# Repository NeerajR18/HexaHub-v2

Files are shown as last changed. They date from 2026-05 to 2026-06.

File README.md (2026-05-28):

Zine

# HexaHub-v2

NOTE: This is still a WIP project. Follow at your own risk!

A USB 2.0 Hub using the SL2.1A which has 4 downstream USB-A port and USB-C upstream port, with ESD and overcurrent protection enclosed in a 3D printed case with a hexagon-shaped PCB.

This USB Hub was made because of unavailability of the SL2.1S IC, which was used in the previous version and also as an improved version with polyfuses and ESD protection diodes.

This Hub was designed using KiCad and Autodesk Fusion for PCB and CAD Design. Fusion was also used for the case renders.

Made for Hack Club Fallout.

# PCB

- Schematic


- PCB without Ground Plane


- Overall PCB


# CAD

- Full Assembly


- Exploded View


# Renders
- Enclosed
HexahubV2_2026-May-25_07-50-50AM-000_CustomizedView698346096
- Exploded
HexahubV2_2026-May-25_08-39-06AM-000_CustomizedView19009070130

# Build Guide
- Acquire your parts from your favourite platform.
- Order the PCB from your manufacturer
- Solder the components to the PCB
- 3D print the case, place PCB in the bottom, then close the top.
- Done!
If any footprints or 3D models are missing, you may use the footprints, symbols etc. from the Assets folder. Check your project folder and paths before importing.

# Bill of Materials

| MPN | Designator | Package | Quantity | Unit Price | Price (Ext.) | LCSC Link |
|---|---|---|---|---|---|---|
| SL2.1A | U1 | SOP-16 | 5 | 0.2677 | 1.34 | https://www.lcsc.com/product-detail/C6798314.html |
| 10.0 QHHTZB6.3 | J1 | SMD | 10 | 0.0665 | 0.67 | https://www.lcsc.com/product-detail/C668591.html |
| 676430910 | J2, J3, J4, J5 | Through Hole, Right Angle | 4 | 0.9415 | 3.77 | https://www.lcsc.com/product-detail/C2798029.html |
| 1206L200/24NR | F1 | 1206 | 5 | 0.1404 | 0.70 | https://www.lcsc.com/product-detail/C42396578.html |
| 1206L005/110WR | F2, F3, F4, F5 | 1206 | 5 | 0.1387 | 0.69 | https://www.lcsc.com/product-detail/C46422913.html |
| PRTR5V0U2X-ES | D1, D2, D3, D4, D5 | SOT-143 | 5 | 0.0404 | 0.20 | https://www.lcsc.com/product-detail/C5180302.html |
| X32258MOB4SI | Y1 | SMD3225-4P | 5 | 0.1738 | 0.87 | https://www.lcsc.com/product-detail/C2682775.html |
| RC0603FR-075K1L | R1, R2 | 0603 | 100 | 0.0018 | 0.18 | https://www.lcsc.com/product-detail/C105580.html |
| CL10A106KP8NNNC | C1, C2, C3, C4, C5, C6 | 0603 | 20 | 0.0108 | 0.22 | https://www.lcsc.com/product-detail/C19702.html |
| CC0402JRNPO9BN220 | C7, C8 | 0402 | 100 | 0.0012 | 0.12 | https://www.lcsc.com/product-detail/C106203.html |
| JLCPCB(PCB+shipping) | - | - | 5 | 4.66 | 14 | jlcpcb.com
| Total | - | - | - | 22.76 | - |
Apart from the IC, you may choose any brand of parts but with same package.

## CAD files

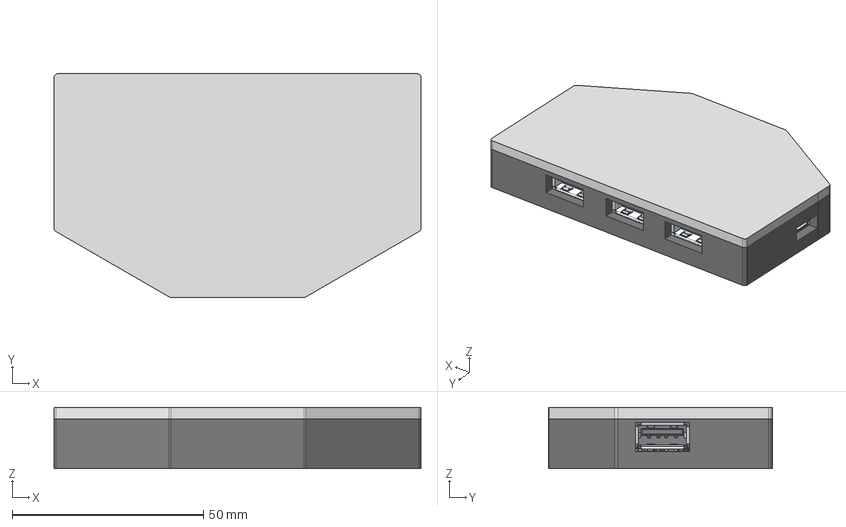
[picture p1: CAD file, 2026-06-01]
CAD/HexahubV2-assembled.step
96.0 x 58.5 x 16.0 mm

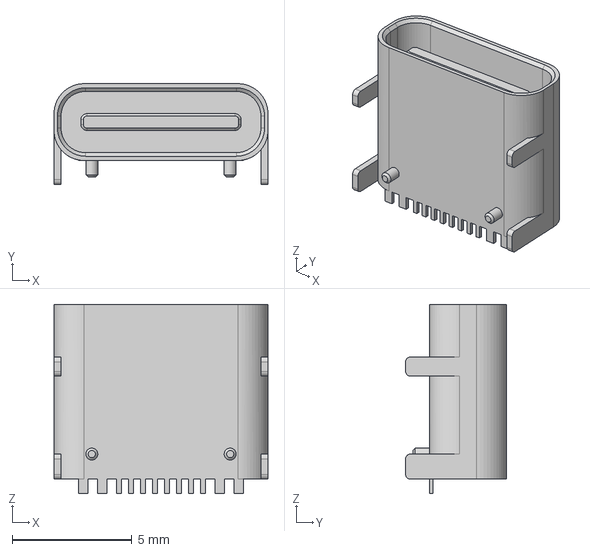
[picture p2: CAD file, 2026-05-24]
Assets/Type-C/HRO TYPE-C-31-M-12.step
8.94 x 4.21 x 7.90 mm

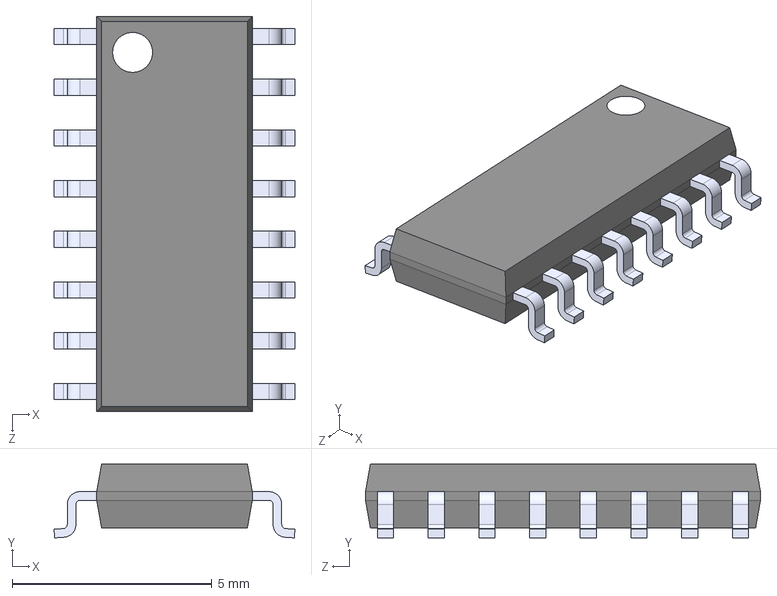
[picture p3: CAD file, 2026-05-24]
PCB/SL2.1A/SL2.1A.step
6.04 x 1.85 x 9.90 mm

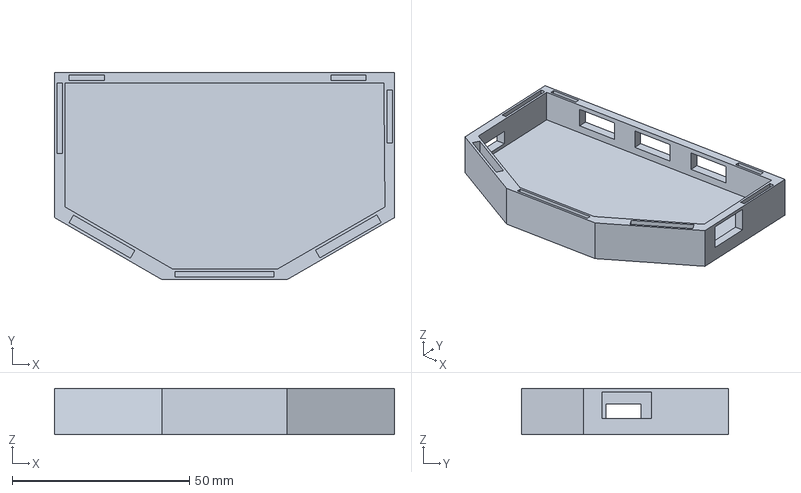
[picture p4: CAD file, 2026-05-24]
Production/STEP files/HexahubV2-bottom.step
96.0 x 58.5 x 13.0 mm
C_0402_1005Metric x 2
SOT-143 x 5
SL2.1A
Fuse_1206_3216Metric x 5
C_0603_1608Metric x 6
R_0603_1608Metric x 2
USB_A_Molex_67643_Horizontal x 4
Crystal_SMD_3225-4Pin_3.2x2.5mm
HRO TYPE-C-31-M-12
HexaHubV2_copper
HexaHubV2_PCB

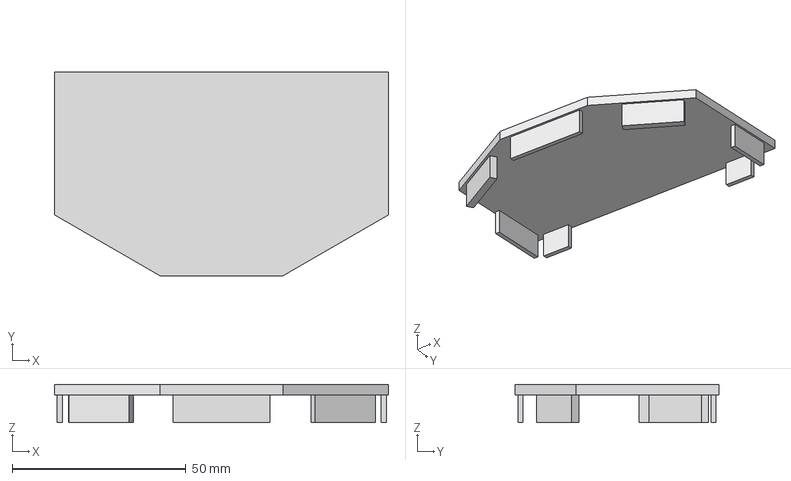
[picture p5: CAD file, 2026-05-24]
Production/STEP files/HexahubV2-top.step
96.0 x 58.5 x 11.0 mm
C_0402_1005Metric x 2
SOT-143 x 5
SL2.1A
Fuse_1206_3216Metric x 5
C_0603_1608Metric x 6
R_0603_1608Metric x 2
USB_A_Molex_67643_Horizontal x 4
Crystal_SMD_3225-4Pin_3.2x2.5mm
HRO TYPE-C-31-M-12
HexaHubV2_copper
HexaHubV2_PCB

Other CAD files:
CAD/HexahubV2-top.step
CAD/HexahubV2-bottom.step
CAD/HexahubV2.f3z
Production/STL files/HexahubV2-bottom.stl
Production/STL files/HexahubV2-top.stl

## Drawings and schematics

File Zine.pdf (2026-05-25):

V2

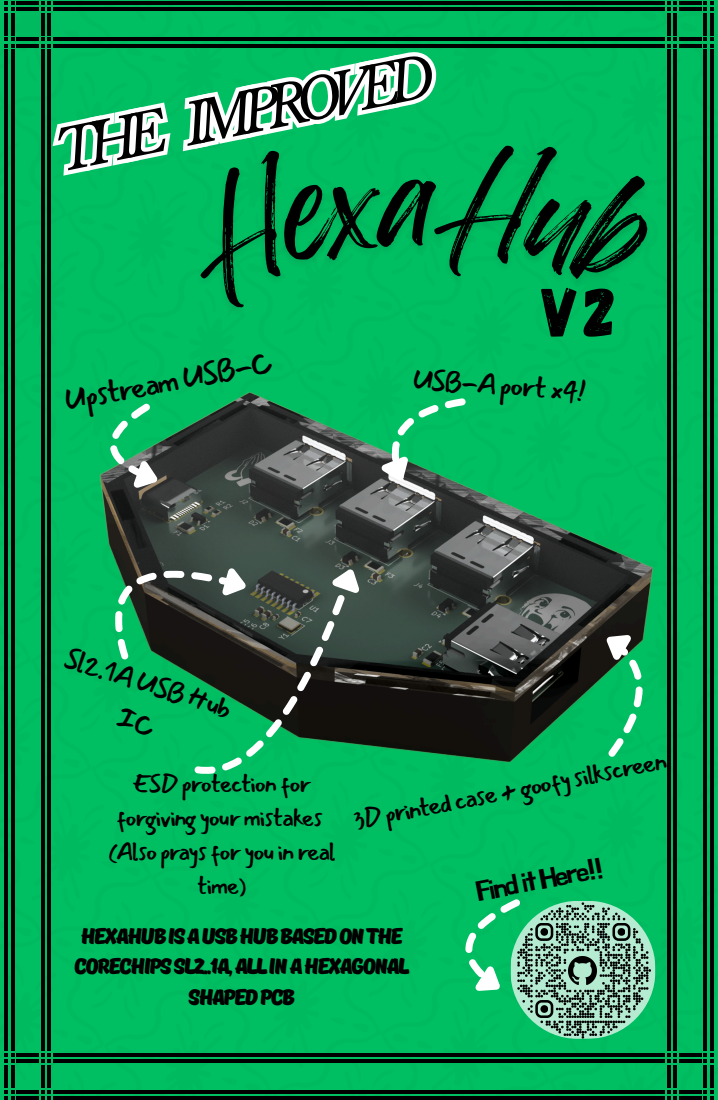
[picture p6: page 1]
UpstreamUSB-C; USBHub C; USB-Aportx4!; 3Dprintedcase+goofysilkscreen; ESDprotectionfor forgivingyourmistakes (Alsopraysforyouinreal time); HexaHubisaUSBHubbasedonthe CoreChipsSL2..1A,allinahexagonal shapedPCB; FinditHere!!

THE IMPROVED IMPROVED

THE IMPROVED HexaHub

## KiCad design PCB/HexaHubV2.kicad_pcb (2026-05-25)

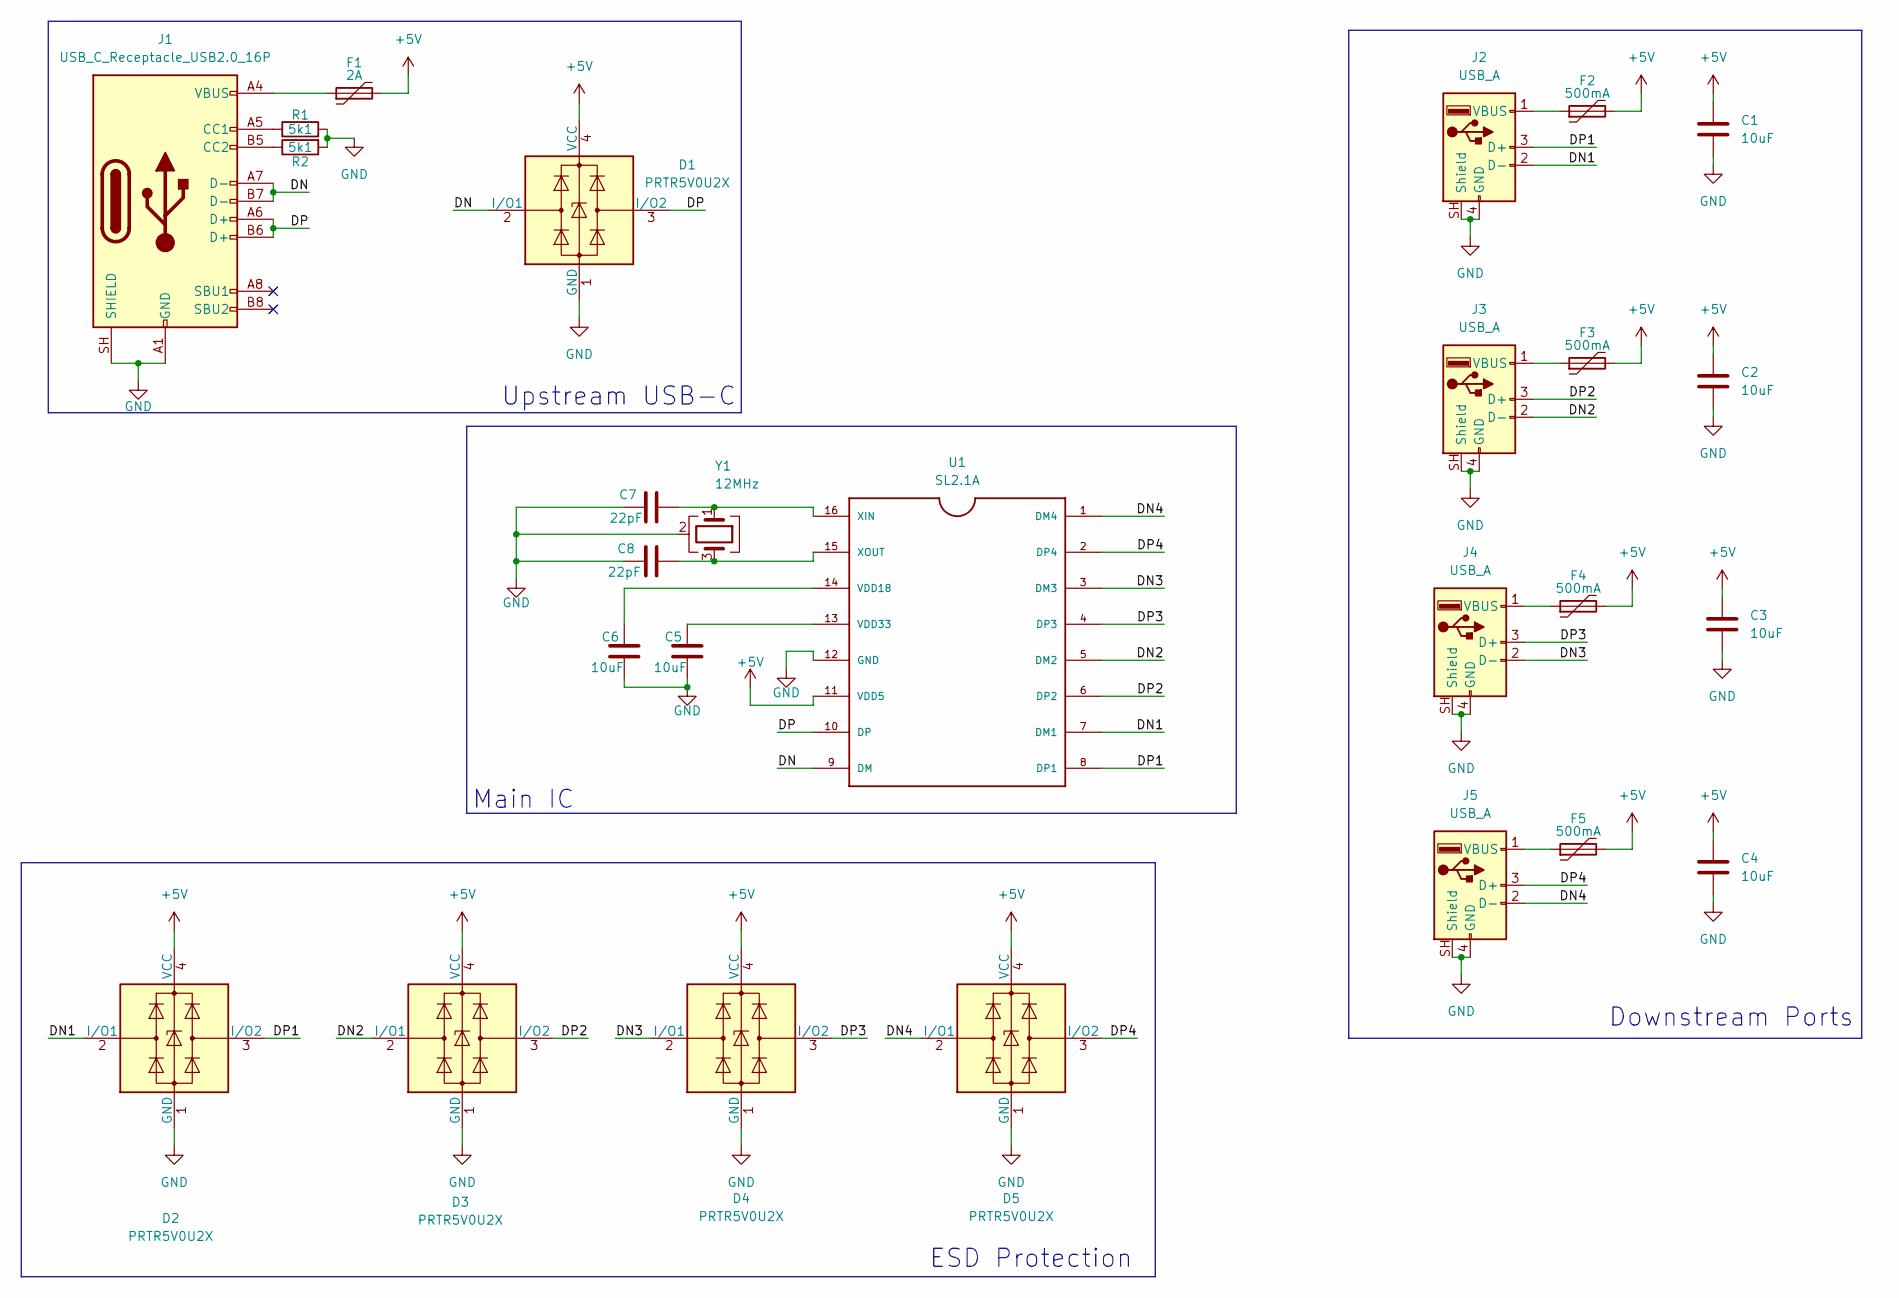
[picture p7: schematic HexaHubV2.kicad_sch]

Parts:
C1, C2, C3, C4, C5, C6: 10uF; C_0603_1608Metric
C7, C8: 22pF; C_0402_1005Metric
D1, D2, D3, D4, D5: PRTR5V0U2X; SOT-143
F1: 2A; Fuse_1206_3216Metric
F2, F3, F4, F5: 500mA; Fuse_1206_3216Metric
J1: USB_C_Receptacle_USB2.0_16P; USB_C_Receptacle_HRO_TYPE-C-31-M-12
J2, J3, J4, J5: USB_A; USB_A_Molex_67643_Horizontal
R1, R2: 5k1; R_0603_1608Metric
U1: SL2.1A; SO16
Y1: 12MHz; Crystal_SMD_3225-4Pin_3.2x2.5mm

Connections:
+5V: C1.1, C2.1, C3.1, C4.1, D1.4 (VCC), D2.4 (VCC), D3.4 (VCC), D4.4 (VCC), D5.4 (VCC), F1.2, F2.2, F3.2, F4.2, F5.2, U1.11 (VDD5)
/DN: D1.2 (I/O1), J1.A7 (D-), J1.B7 (D-), U1.9 (DM)
/DN1: D2.2 (I/O1), J2.2 (D-), U1.7 (DM1)
/DN2: D3.2 (I/O1), J3.2 (D-), U1.5 (DM2)
/DN3: D4.2 (I/O1), J4.2 (D-), U1.3 (DM3)
/DN4: D5.2 (I/O1), J5.2 (D-), U1.1 (DM4)
/DP: D1.3 (I/O2), J1.A6 (D+), J1.B6 (D+), U1.10 (DP)
/DP1: D2.3 (I/O2), J2.3 (D+), U1.8 (DP1)
/DP2: D3.3 (I/O2), J3.3 (D+), U1.6 (DP2)
/DP3: D4.3 (I/O2), J4.3 (D+), U1.4 (DP3)
/DP4: D5.3 (I/O2), J5.3 (D+), U1.2 (DP4)
GND: C1.2, C2.2, C3.2, C4.2, C5.1, C6.1, C7.2, C8.2, D1.1 (GND), D2.1 (GND), D3.1 (GND), D4.1 (GND), D5.1 (GND), J1.A1 (GND), J1.A12 (GND), J1.B1 (GND), J1.B12 (GND), J1.SH (SHIELD), J2.4 (GND), J2.SH (Shield), J3.4 (GND), J3.SH (Shield), J4.4 (GND), J4.SH (Shield), J5.4 (GND), J5.SH (Shield), R1.2, R2.2, U1.12 (GND), Y1.2 (G), Y1.4 (G)
unnamed: F1.1, J1.A4 (VBUS), J1.A9 (VBUS), J1.B4 (VBUS), J1.B9 (VBUS)
unnamed: J1.A5 (CC1), R1.1
unnamed: J1.B5 (CC2), R2.1
unnamed: F2.1, J2.1 (VBUS)
unnamed: F3.1, J3.1 (VBUS)
unnamed: F4.1, J4.1 (VBUS)
unnamed: F5.1, J5.1 (VBUS)
unnamed: C6.2, U1.14 (VDD18)
unnamed: C5.2, U1.13 (VDD33)
unnamed: C7.1, U1.16 (XIN), Y1.1
unnamed: C8.1, U1.15 (XOUT), Y1.3

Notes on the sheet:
ESD Protection
Main IC
Downstream Ports
Upstream USB-C

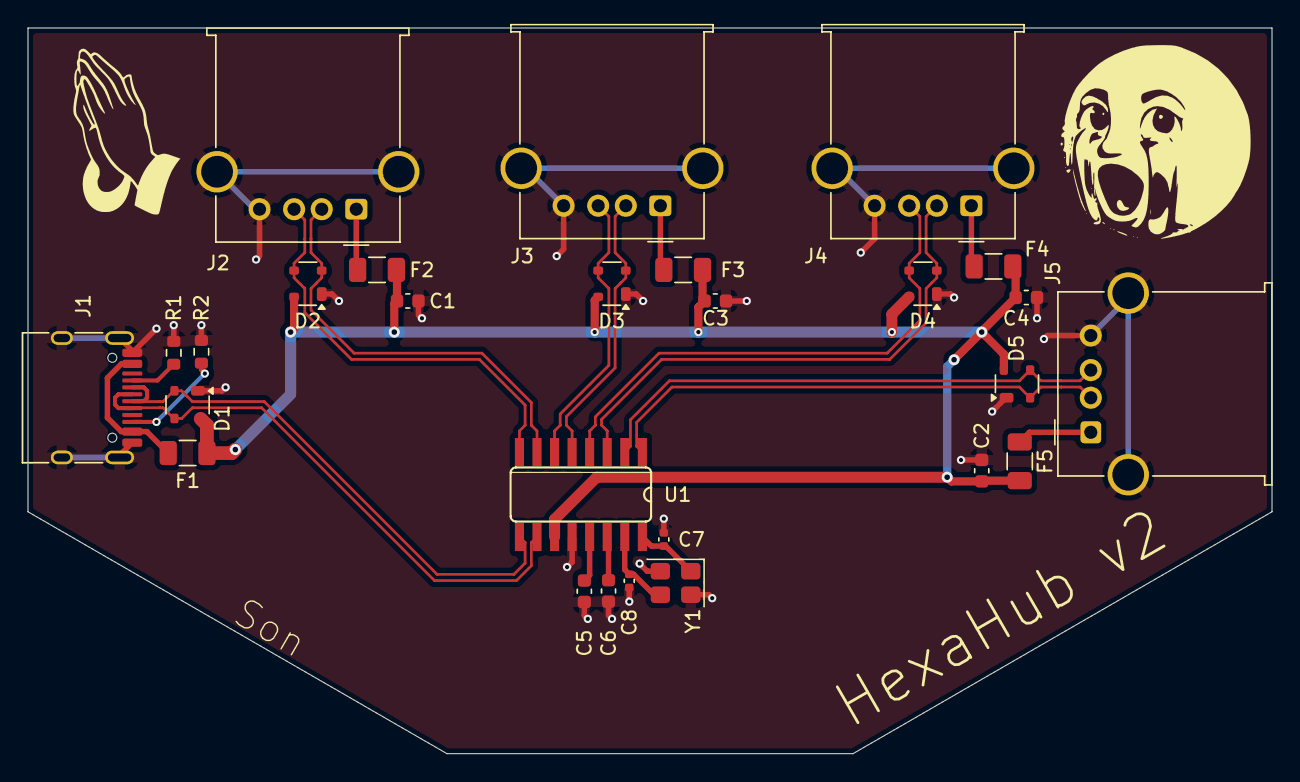
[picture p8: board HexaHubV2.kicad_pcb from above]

Board: 2 copper layers, 90.0 x 52.5 mm, 27 parts (0 on the bottom side), 23 nets.

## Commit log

2026-05-24 Added PCB files and gerbers
    [HexaHubV2.kicad_pcb, HexaHubV2.kicad_sch]
2026-05-24 Slight changes to PCB and updated gerbers
    [HexaHubV2.kicad_pcb, HexaHubV2.kicad_sch]
2026-05-24 Added BOM, footprints and 3d models
    BOM and footprint, symbol and 3d model of SL2.1A and Type-C port
    [BOM.csv, SL2.1A.step]
2026-05-24 Added Type-C 3D model
    [HRO TYPE-C-31-M-12.step, SL2.1A.step]
2026-05-24 Added CAD files
    [HexahubV2-assembled.step, HexahubV2-bottom.step, HexahubV2-bottom.stl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]
2026-05-24 Updated README
    Added project details, build guide, and bill of materials to README.
2026-05-25 Slight changes to PCB
    [HexaHubV2.kicad_pcb, SL2.1A.step]
2026-05-25 Added zine page and renders, updated PCB images
2026-06-01 updated CAD files
    [HexahubV2-assembled.step, HexahubV2-bottom.step, HexahubV2-top.step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]
